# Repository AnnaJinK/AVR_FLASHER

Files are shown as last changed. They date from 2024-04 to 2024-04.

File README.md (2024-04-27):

## What is this?

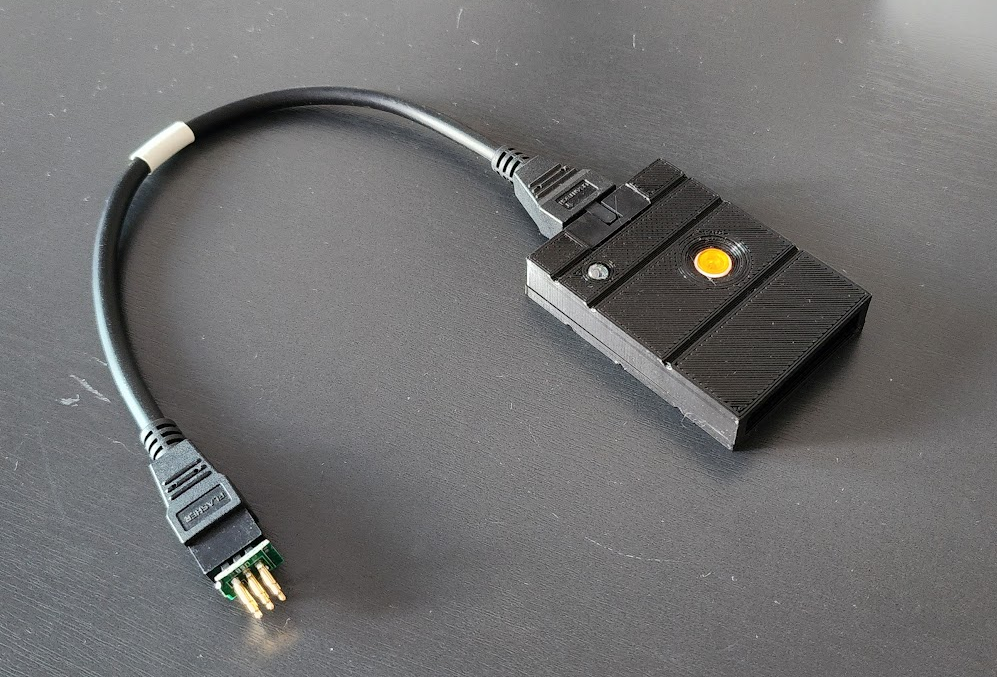
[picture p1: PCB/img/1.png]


SD 카드에 저장된 펌웨어를 타겟 AVR 장치로 플래싱하는 Standalone AVR Programmer 입니다.  
이 장치는 PC 가 필요없으며 간편하게 버튼 클릭만으로 타겟 장치의 IC 를 판별하여 펌웨어를 쓸수 있습니다.  
또한 ATtiny 부터 ATmega328PB 및 ATmega2560 등 ATmel 사의 다양한 AVR 을 지원합니다.

본 프로젝트는 [Gammon Forum](http://www.gammon.com.au/forum/?id=11638)의 내용을 바탕으로 제작되었습니다.

## Introduction

빌드된 펌웨어 파일 `firmaware.hex` 을 SD 카드에 옮겨준 후 장치에 삽입하고 버튼 만 누르면 됩니다.  
PlatformIO 에서 빌드된 펌웨어는 `firmaware.hex` 이름으로 `.pio/build` 폴더에 생성됩니다.  
ArduinoIDE 를 사용하는 경우 `Ctrl + Alt + S` 로 컴파일된 바이너리 파일 생성 후 `firmaware.hex` 로 이름을 바꿔서 사용하면 됩니다.

### Inside

PCB는 ATmega328P 제품을 사용하여 제작되었습니다.  
필요한 경우 ATmega2560 나 ATmega32u4 같은 다른 IC 를 사용하여 만들수도 있습니다.

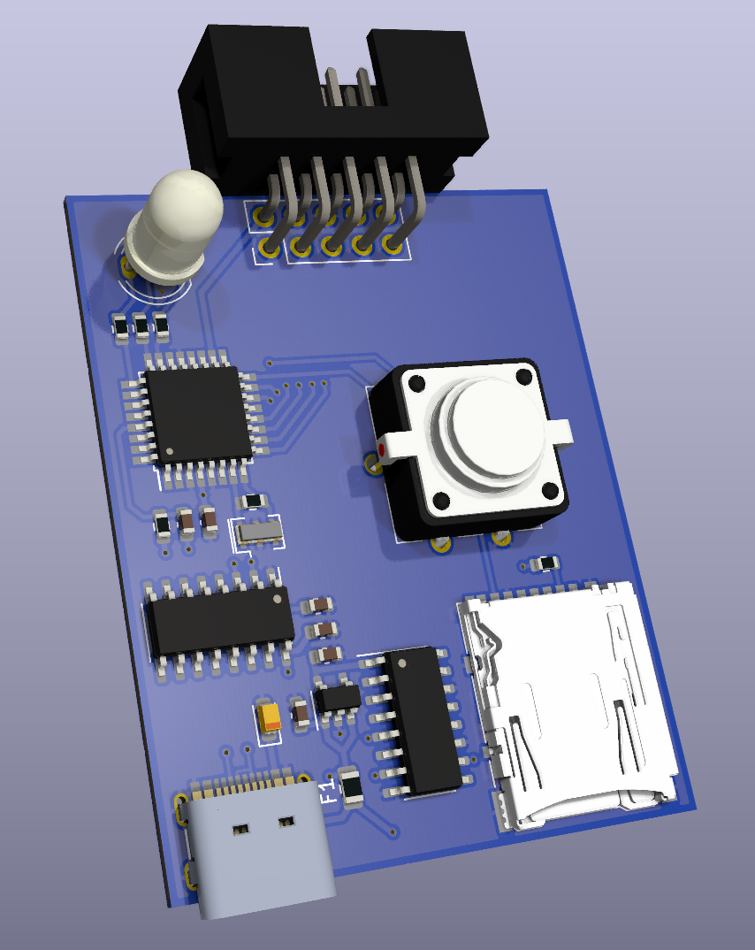
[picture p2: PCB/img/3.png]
  
  
USB C 포트는 시리얼 통신을 지원하며, 아두이노 부트로더 내장시 USB 를 통해 펌웨어를 쉽게 수정할 수 있습니다.  
부트로더가 내장되지 않은 IC 를 사용하는 경우 PCB 에 실장되는 IC를 위한 ICSP 가 없기 때문에 사전에 프로그램을 다운받는 것이 좋습니다.  
저렴하고 구하기쉬운 최소한의 부품들로 구성하였기 때문에 쉽게만들 수 있습니다.

자세한 내용은 [회로도](PCB/Schematic.pdf)를 참조하세요.

회로도와 부품 배치 데이터, 케이스 3D 모델, 거버파일은 PCB 폴더에 있습니다.

### Video

Video (https://youtu.be/CiSJQsz9dUg)

## CUSTOM FUSE

**이 기능은 사용시 주의가 필요합니다.**  
**CUSTOM FUSE 는 잘못 사용하면 IC 를 더 이상 사용할 수 없는 상태가 될 수 있습니다.**  
퓨즈 설정에 익숙하지 않다면 [퓨즈 계산기](https://www.engbedded.com/fusecalc/) 를 이용하는 것이 좋습니다.

`platformio.ini` 애서 CUSTOM_FUSE 활성화 방법입니다. (`ArduinoIDE` 는 스케치 상단에 정의합니다.)  
SD 카드를 사용하는 `CUSTOM_FUSE = 2`, `DEBUG_LV = 0` 가 기본 설정입니다.

```c
// File : platformio.ini
// @PlatformIO

build_flags =
; CUSTOM_FUSE 0 CUSTOM_FUSE 사용안함, 타겟 장치의 기본 세팅값 사용
; CUSTOM_FUSE 1 fuse.h 파일에 저장된 퓨즈세팅 사용
; CUSTOM_FUSE 2 SD 카드의 config.ini 파일로 부터 퓨즈 세팅 읽어옴
  -D CUSTOM_FUSE=2
; DEBUG_LV 0 디버그 모드 끔, 메모리 확보를 위해 끄는 것을 권장합니다
; DEBUG_LV 1 정의된 모든 동작을 모니터링
; DEBUG_LV 2 타겟 IC 식별과 SD 카드 퓨즈 세팅 동작 위주
  -D DEBUG_LV=0
  -D SERIAL_DISABLE=false ; 시리얼 통신 활성화
```

### `fuse.h` 파일을 사용한 CUSTOM_FUSE 설정

`platformio.ini` 의 내용을 다음과 같이 수정 한 후 AVR Programmer 에 업로드합니다.
```c
// File : platformio.ini
// @PlatformIO

build_flags =
  -D CUSTOM_FUSE=1
  -D DEBUG_LV=0
  -D SERIAL_DISABLE=true
```

`fuse.h` 를 사용한 방법은 메모리를 더 적게 사용하지만 장치를 매번 다시 컴파일 해줘야하는 단점이 있습니다.

```c
// File : src/fuse.h
/*
 * IC 와 퓨즈 정보를 아래 양식에 맞게 작성하여 사용합니다.
 * Available IC Table 에 정의된 이름과 동일하게 정의해야 합니다. (대소분자 구분)
 */
#ifdef ATmega32U4
#define AVR_CORE "ATmega32U4"
const byte low_fuses = 0xFF;
const byte high_fuses = 0xD8;
const byte extended_fuses = 0xCB;
const byte lock_bits = 0xFF;
#endif
```

`setting.h` 에 본인이 사용할 IC 를 정의합니다.
```c
// File : src/setting.h
#if CUSTOM_FUSE == 1
#define ATmega32U4  // 커스텀 퓨즈세팅을 사용할 IC 를 정의합니다.
#include "fuse.h"
byte custom_fuses[5] = {
    low_fuses,
    high_fuses,
    extended_fuses,
    lock_bits,
};
#elif CUSTOM_FUSE == 2
String AVR_CORE = "";
byte custom_fuses_sd[5];
#endif

```

### SD 카드의 `config.ini` 파일을 사용한 CUSTOM_FUSE 설정

SD 에 저장된 설정값을 사용하는 방법은 메모리를 조금 더 사용합니다.  
AVR Programmer의 펌웨어 변경없이 원하는 Fuse 값을 SD 카드에 넣어주기만 하면 되기 때문에 좀 더 편리합니다.  
단점으로 `DEBUG_LV 1` 과 함께 사용시 시스템 메모리가 2KB 이하인 IC는 메모리 부족으로 IC 가 리셋 될수 있습니다.  
따라서 CUSTOM FUSE 설정에 SD 카드 모드 사용시 `DEBUG_LV 0` 또는 `DEBUG_LV 2` 로 설정해야 합니다.

먼저 `platformio.ini` 의 내용을 다음과 같이 수정하여 AVR Programmer 에 업로드합니다
```c
// File : platformio.ini
// @PlatformIO

build_flags =
  -D CUSTOM_FUSE=2
  -D DEBUG_LV=0
  -D SERIAL_DISABLE=true
```

그 다음 SD 카드에 다음과 같이 `config.ini` 파일을 생성합니다.  
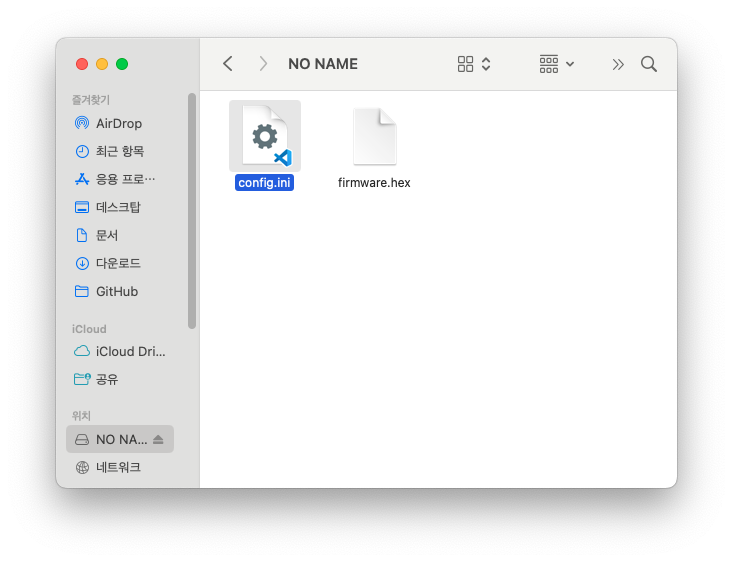
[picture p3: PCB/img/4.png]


`config.ini` 파일 내용은 다음과 같은 양식으로 작성합니다.

```
ATmega328P:FFDAFDFF
```

':' 를 구분 자로 사용하며 앞 쪽에는 IC 의 이름, 뒷 쪽에는 Fuse 설정을 적습니다.  
Fuse 의 순서는 왼쪽 부터 Low/High/Extended/Lockbits 입니다.

## Available IC Table

```c
// Atmega 칩들의 시그니처 코드입니다. 이 데이터들을 기준으로 타겟 칩을 인식합니다.
const signatureType signatures[] PROGMEM = {
    //     signature        description   flash size   bootloader  flash  fuse     timed
    //                                                     size    page    to      writes
    //                                                             size   change

    // Attiny84 family
    {{0x1E, 0x91, 0x0B}, "ATtiny24", 2 * kb, 0, 32, NO_FUSE, false},
    {{0x1E, 0x92, 0x07}, "ATtiny44", 4 * kb, 0, 64, NO_FUSE, false},
    {{0x1E, 0x93, 0x0C}, "ATtiny84", 8 * kb, 0, 64, NO_FUSE, false},

    // Attiny85 family
    {{0x1E, 0x91, 0x08}, "ATtiny25", 2 * kb, 0, 32, NO_FUSE, false},
    {{0x1E, 0x92, 0x06}, "ATtiny45", 4 * kb, 0, 64, NO_FUSE, false},
    {{0x1E, 0x93, 0x0B}, "ATtiny85", 8 * kb, 0, 64, NO_FUSE, false},

    // Atmega328 family
    {{0x1E, 0x92, 0x0A}, "ATmega48PA", 4 * kb, 0, 64, NO_FUSE, false},
    {{0x1E, 0x93, 0x0F}, "ATmega88PA", 8 * kb, 256, 128, extFuse, false},
    {{0x1E, 0x94, 0x0B}, "ATmega168PA", 16 * kb, 256, 128, extFuse, false},
    {{0x1E, 0x94, 0x06}, "ATmega168V", 16 * kb, 256, 128, extFuse, false},
    {{0x1E, 0x95, 0x0F}, "ATmega328P", 32 * kb, 512, 128, highFuse, false},
    {{0x1E, 0x95, 0x16}, "ATmega328PB", 32 * kb, 512, 128, highFuse, false},
    {{0x1E, 0x95, 0x14}, "ATmega328", 32 * kb, 512, 128, highFuse, false},

    // Atmega644 family
    {{0x1E, 0x94, 0x0A}, "ATmega164P", 16 * kb, 256, 128, highFuse, false},
    {{0x1E, 0x95, 0x08}, "ATmega324P", 32 * kb, 512, 128, highFuse, false},
    {{0x1E, 0x96, 0x0A}, "ATmega644P", 64 * kb, 1 * kb, 256, highFuse, false},

    // Atmega2560 family
    {{0x1E, 0x96, 0x08}, "ATmega640", 64 * kb, 1 * kb, 256, highFuse, false},
    {{0x1E, 0x97, 0x03}, "ATmega1280", 128 * kb, 1 * kb, 256, highFuse, false},
    {{0x1E, 0x97, 0x04}, "ATmega1281", 128 * kb, 1 * kb, 256, highFuse, false},
    {{0x1E, 0x98, 0x01}, "ATmega2560", 256 * kb, 1 * kb, 256, highFuse, false},

    {{0x1E, 0x98, 0x02}, "ATmega2561", 256 * kb, 1 * kb, 256, highFuse, false},

    // AT90USB family
    {{0x1E, 0x93, 0x82}, "At90USB82", 8 * kb, 512, 128, highFuse, false},
    {{0x1E, 0x94, 0x82}, "At90USB162", 16 * kb, 512, 128, highFuse, false},

    // Atmega32U2 family
    {{0x1E, 0x93, 0x89}, "ATmega8U2", 8 * kb, 512, 128, highFuse, false},
    {{0x1E, 0x94, 0x89}, "ATmega16U2", 16 * kb, 512, 128, highFuse, false},
    {{0x1E, 0x95, 0x8A}, "ATmega32U2", 32 * kb, 512, 128, highFuse, false},

    // Atmega32U4 family -  (datasheet is wrong about flash page size being 128 words)
    {{0x1E, 0x94, 0x88}, "ATmega16U4", 16 * kb, 512, 128, highFuse, false},
    {{0x1E, 0x95, 0x87}, "ATmega32U4", 32 * kb, 512, 128, highFuse, false},

    // ATmega1284P family
    {{0x1E, 0x97, 0x05}, "ATmega1284P", 128 * kb, 1 * kb, 256, highFuse, false},
    {{0x1E, 0x97, 0x06}, "ATmega1284", 128 * kb, 1 * kb, 256, highFuse, false},

    // ATtiny4313 family
    {{0x1E, 0x91, 0x0A}, "ATtiny2313A", 2 * kb, 0, 32, NO_FUSE, false},
    {{0x1E, 0x92, 0x0D}, "ATtiny4313", 4 * kb, 0, 64, NO_FUSE, false},

    // ATtiny13 family
    {{0x1E, 0x90, 0x07}, "ATtiny13A", 1 * kb, 0, 32, NO_FUSE, false},

    // Atmega8A family
    {{0x1E, 0x93, 0x07}, "ATmega8A", 8 * kb, 256, 64, highFuse, true},

    // ATmega64rfr2 family
    {{0x1E, 0xA6, 0x02}, "ATmega64rfr2", 256 * kb, 1 * kb, 256, highFuse, false},
    {{0x1E, 0xA7, 0x02}, "ATmega128rfr2", 256 * kb, 1 * kb, 256, highFuse, false},
    {{0x1E, 0xA8, 0x02}, "ATmega256rfr2", 256 * kb, 1 * kb, 256, highFuse, false},

};
```

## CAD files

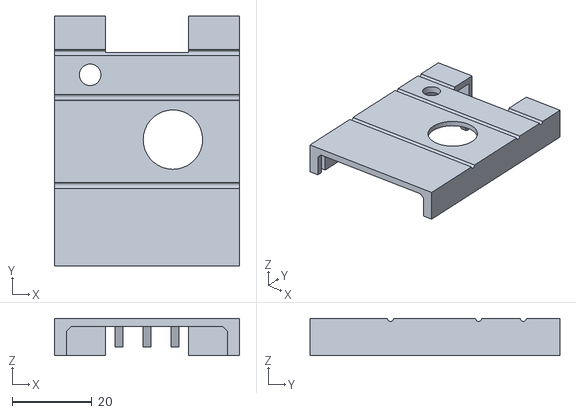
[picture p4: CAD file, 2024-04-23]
PCB/3D Print CASE/AVR_FLASHER - SLIM_TOP.STL
46.4 x 62.7 x 9.30

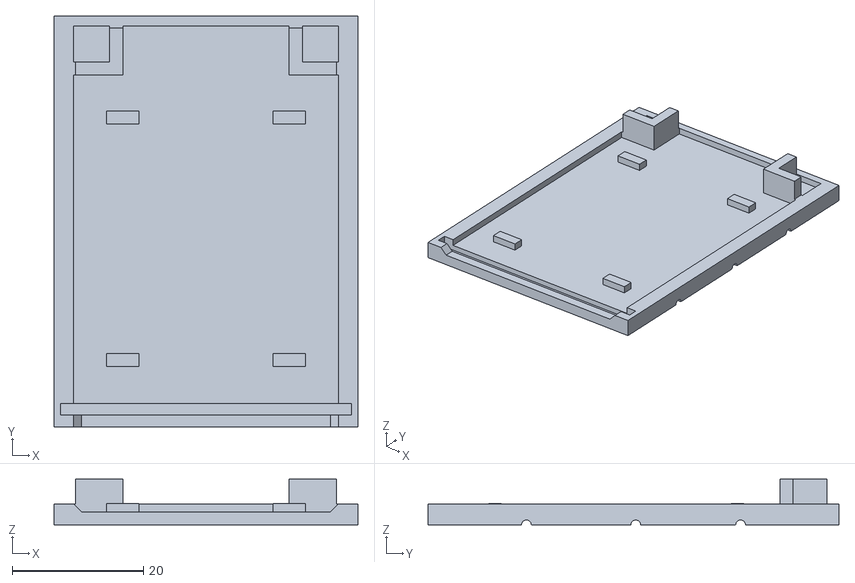
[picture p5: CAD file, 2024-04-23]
PCB/3D Print CASE/AVR_FLASHER - SLIM_BOT.STL
46.4 x 62.7 x 7.00

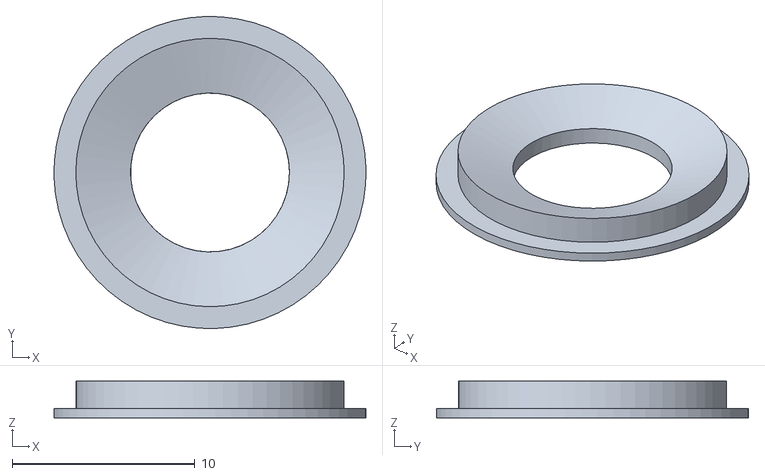
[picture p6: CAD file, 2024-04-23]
PCB/3D Print CASE/AVR_FLASHER - SLIM_HOLE.STL
17.1 x 17.1 x 2.00

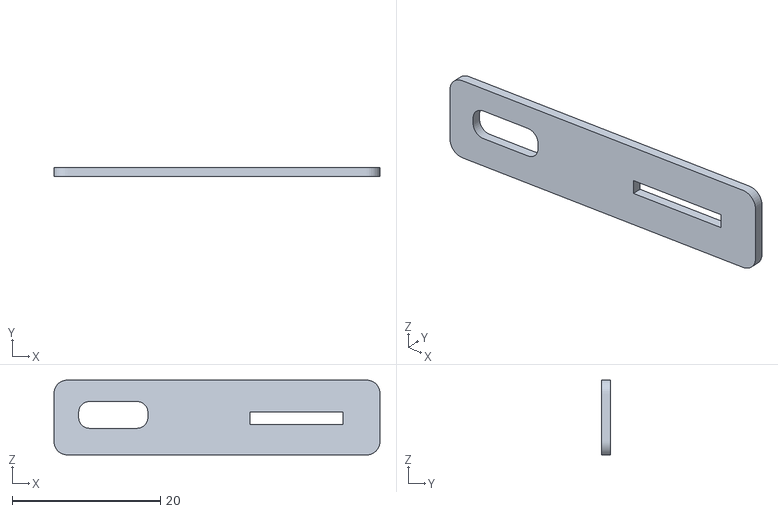
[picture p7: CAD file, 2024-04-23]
PCB/3D Print CASE/AVR_FLASHER - SLIM_IO.STL
44.0 x 1.20 x 10.1

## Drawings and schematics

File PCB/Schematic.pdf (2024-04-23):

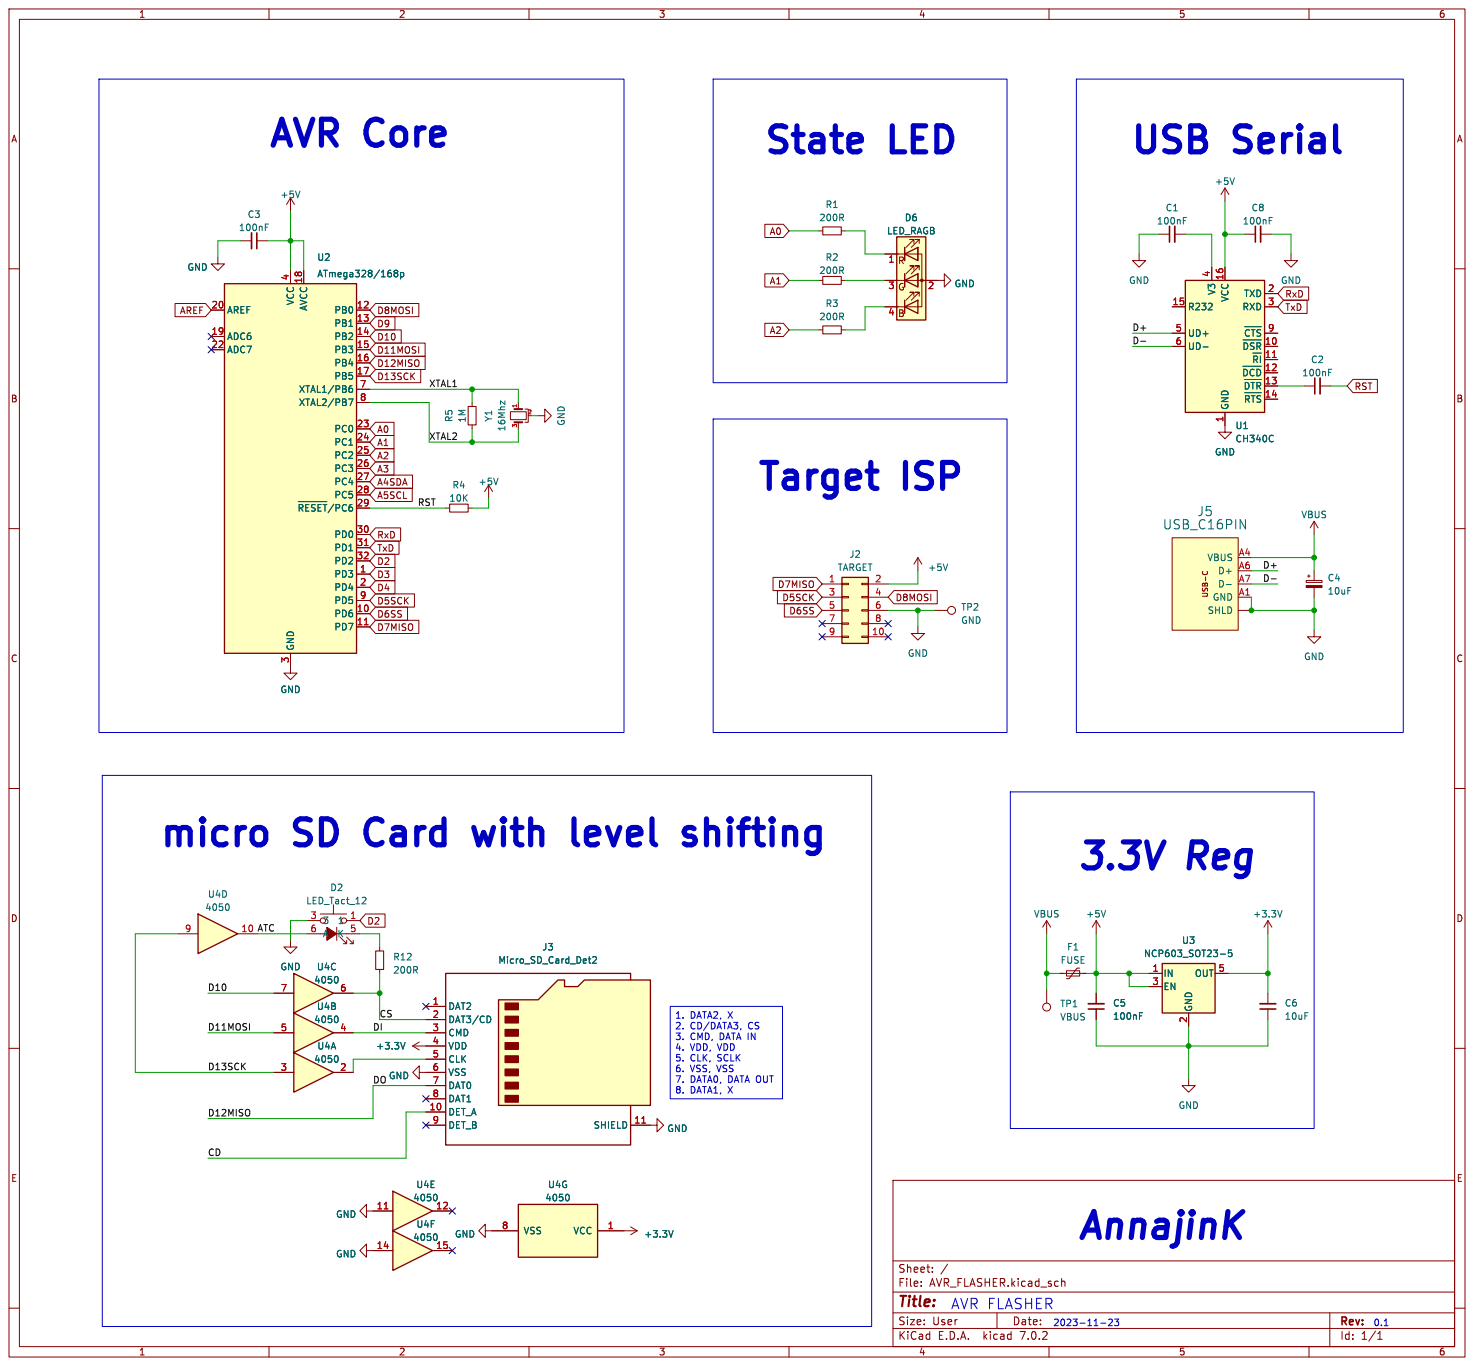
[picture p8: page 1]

1 ~{DSR} 10 ~{RI} 11 ~{DCD} 12 ~{DTR} 13 ~{RTS} 14 R232 15 VCC 16 TXD 2 RXD 3 V3

4 UD+ 5 UD- 6 ~{CTS}9 GND

100nF GND USB-C GND A1 VBUS A4 D+ A6 D- A7 SHLD

2023-11-23 3.3V Reg micro SD Card with level shifting

Id: 1/1 Title: File: AVR_FLASHER.kicad_sch Sheet: /

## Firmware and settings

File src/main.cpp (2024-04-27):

#include <Arduino.h>
#include <SDFat.h>
#include <sdios.h>

#include "setting.h"

// SD 카드에서 읽을 고정 파일 이름 (루트 디렉터리)
const char wantedFile[] = "firmware.hex";
const char configFile[] = "config.ini";

/*
  For more details, photos, wiring, instructions, see:
    http://www.gammon.com.au/forum/?id=11638
  Copyright 2012 Nick Gammon. Addeded code forr fuse burning by Dan Geiger 2023.


  PERMISSION TO DISTRIBUTE

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

  LIMITATION OF LIABILITY

  The software is provided "as is", without warranty of any kind, express or implied,
  including but not limited to the warranties of merchantability, fitness for a particular
  purpose and noninfringement. In no event shall the authors or copyright holders be liable
  for any claim, damages or other liability, whether in an action of contract,
  tort or otherwise, arising from, out of or in connection with the software
  or the use or other dealings in the software.
*/

// const char Version[] = "1.3dg";

// file system object
SdFat sd;

// 각 칩에 대한 시그니처 및 기타 관련 데이터를 저장하는 구조체
#include "signature.h"

// 함수 선언
void writeFuse(const byte newValue, const byte instruction);

//"times" 만큼 "interval" 지연시간으로 한 개 또는 두 개의 LED를 깜박입니다.
// 깜빡임 동작은 1초 대기 후 "repeat" 횟수만큼 다시 반복됩니다
void blink(const int whichLED1, const int whichLED2, const byte times = 1, const unsigned long repeat = 1, const unsigned long interval = 100) {
    for (unsigned long i = 0; i < repeat; i++) {
        for (byte j = 0; j < times; j++) {
            digitalWrite(whichLED1, HIGH);
            if (whichLED2 != noLED) digitalWrite(whichLED2, HIGH);
            delay(interval);
            digitalWrite(whichLED1, LOW);
            if (whichLED2 != noLED) digitalWrite(whichLED2, LOW);
            delay(interval);
        }  // end of for loop
        if (i < (repeat - 1)) delay(10);
    }  // end of repeating the sequence
}  // end of blink

void ShowMessage(const byte which) {
    // first turn off all LEDs
    digitalWrite(errorLED, LOW);
    digitalWrite(workingLED, LOW);
    digitalWrite(readyLED, LOW);

    // now flash an appropriate sequence
    switch (which) {
        // problems with SD card or finding the file
        case MSG_NO_SD_CARD:
            debugln_1("MSG_NO_SD_CARD");
            blink(errorLED, noLED, 1, 5);
            break;
        case MSG_CANNOT_OPEN_FILE:
            debugln_1("MSG_CANNOT_OPEN_FILE");
            blink(errorLED, noLED, 2, 5);
            while (!sd.begin(chipSelect, SPI_FULL_SPEED)) {
                ShowMessage(MSG_NO_SD_CARD);
                delay(500);
            }
            break;

        // problems reading the .hex file
        case MSG_LINE_TOO_LONG:
            debugln_1("MSG_LINE_TOO_LONG");
            blink(errorLED, workingLED, 1, 5);
            break;
        case MSG_LINE_TOO_SHORT:
            debugln_1("MSG_LINE_TOO_SHORT");
            blink(errorLED, workingLED, 2, 5);
            break;
        case MSG_LINE_DOES_NOT_START_WITH_COLON:
            debugln_1("MSG_LINE_DOES_NOT_START_WITH_COLON");
            blink(errorLED, workingLED, 3, 5);
            break;
        case MSG_INVALID_HEX_DIGITS:
            debugln_1("MSG_INVALID_HEX_DIGITS");
            blink(errorLED, workingLED, 4, 5);
            break;
        case MSG_BAD_SUMCHECK:
            debugln_1("MSG_BAD_SUMCHECK");
            blink(errorLED, workingLED, 5, 5);
            break;
        case MSG_LINE_NOT_EXPECTED_LENGTH:
            debugln_1("MSG_LINE_NOT_EXPECTED_LENGTH");
            blink(errorLED, workingLED, 6, 5);
            break;
        case MSG_UNKNOWN_RECORD_TYPE:
            debugln_1("MSG_UNKNOWN_RECORD_TYPE");
            blink(errorLED, workingLED, 7, 5);
            break;
        case MSG_NO_END_OF_FILE_RECORD:
            debugln_1("MSG_NO_END_OF_FILE_RECORD");
            blink(errorLED, workingLED, 8, 5);
            break;

        // problems with the file contents
        case MSG_FILE_TOO_LARGE_FOR_FLASH:
            debugln_1("MSG_FILE_TOO_LARGE_FOR_FLASH");
            blink(errorLED, workingLED, 9, 5);
            break;

        // problems programming the chip
        case MSG_CANNOT_ENTER_PROGRAMMING_MODE:
            debugln_1("MSG_CANNOT_ENTER_PROGRAMMING_MODE");
            blink(errorLED, noLED, 3, 5);
            break;
        case MSG_NO_BOOTLOADER_FUSE:
            debugln_1("MSG_NO_BOOTLOADER_FUSE");
            blink(errorLED, noLED, 4, 5);
            break;
        case MSG_CANNOT_FIND_SIGNATURE:
            debugln_1("MSG_CANNOT_FIND_SIGNATURE");
            blink(errorLED, noLED, 5, 5);
            break;
        case MSG_UNRECOGNIZED_SIGNATURE:
            debugln_1("MSG_UNRECOGNIZED_SIGNATURE");
            blink(errorLED, noLED, 6, 5);
            break;
        case MSG_BAD_START_ADDRESS:
            debugln_1("MSG_BAD_START_ADDRESS");
            blink(errorLED, noLED, 7, 5);
            break;
        case MSG_VERIFICATION_ERROR:
            debugln_1("MSG_VERIFICATION_ERROR");
            blink(errorLED, noLED, 8, 5);
            break;
        case MSG_FUSE_PROBLEM:
            debugln_1("MSG_FUSE_PROBLEM");
            blink(errorLED, noLED, 9, 5);
            break;
        case MSG_FLASHED_OK:
            debugln_1("MSG_FLASHED_OK");
            blink(readyLED, noLED, 3, 1);
            break;

        default:
            blink(errorLED, 11, 10);
            break;  // unknown error
    }  // end of switch on which message
}  // end of ShowMessage

// Bit Banged SPI transfer
byte BB_SPITransfer(byte c) {
    byte bit;

    for (bit = 0; bit < 8; bit++) {
        // write MOSI on falling edge of previous clock
        if (c & 0x80)
            BB_MOSI_PORT |= bit(BB_MOSI_BIT);
        else
            BB_MOSI_PORT &= ~bit(BB_MOSI_BIT);
        c <<= 1;

        // read MISO
        c |= (BB_MISO_PORT & bit(BB_MISO_BIT)) != 0;

        // clock high
        BB_SCK_PORT |= bit(BB_SCK_BIT);

        // delay between rise and fall of clock
        delayMicroseconds(BB_DELAY_MICROSECONDS);

        // clock low
        BB_SCK_PORT &= ~bit(BB_SCK_BIT);

        // delay between rise and fall of clock
        delayMicroseconds(BB_DELAY_MICROSECONDS);
    }

    return c;
}  // end of BB_SPITransfer

// 만약 위 테이블에서 시그니처를 찾았다면, foundSig 는 해당 시그니처의 인덱스입니다.
int foundSig = -1;
byte lastAddressMSB = 0;
// 일치하는 프로세서를 위한 현재 시그니처 항목의 사본입니다.
signatureType currentSignature;

// 한 개의 프로그래밍 명령어를 실행합니다. ... b1은 명령, b2, b3, b4는 인수입니다.
// 프로세서는 4번째 전송에서 결과를 반환할 수 있습니다. 이를 반환합니다.
byte program(const byte b1, const byte b2 = 0, const byte b3 = 0, const byte b4 = 0) {
    noInterrupts();
    BB_SPITransfer(b1);
    BB_SPITransfer(b2);
    BB_SPITransfer(b3);
    byte b = BB_SPITransfer(b4);
    interrupts();
    return b;
}  // end of program

// read a byte from flash memory
byte readFlash(unsigned long addr) {
    byte high = (addr & 1) ? 0x08 : 0;  // set if high byte wanted
    addr >>= 1;                         // turn into word address

    // set the extended (most significant) address byte if necessary
    byte MSB = (addr >> 16) & 0xFF;
    if (MSB != lastAddressMSB) {
        program(loadExtendedAddressByte, 0, MSB);
        lastAddressMSB = MSB;
    }  // end if different MSB

    return program(readProgramMemory | high, highByte(addr), lowByte(addr));
}  // end of readFlash

// write a byte to the flash memory buffer (ready for committing)
void writeFlash(unsigned long addr, const byte data) {
    byte high = (addr & 1) ? 0x08 : 0;  // set if high byte wanted
    addr >>= 1;                         // turn into word address
    program(loadProgramMemory | high, 0, lowByte(addr), data);
}  // end of writeFlash

// 두 개의 16진수 문자를 바이트로 변환합니다.
// 에러인 경우 true를 반환하고, 정상인 경우 false를 반환합니다.
bool hexConv(const char *(&pStr), byte &b) {
    if (!isxdigit(pStr[0]) || !isxdigit(pStr[1])) {
        ShowMessage(MSG_INVALID_HEX_DIGITS);
        return true;
    }  // end not hex

    b = *pStr++ - '0';
    if (b > 9) b -= 7;

    // high-order nybble
    b <<= 4;

    byte b1 = *pStr++ - '0';
    if (b1 > 9) b1 -= 7;

    b |= b1;

    return false;  // OK
}  // end of hexConv

// 타겟 장치가 프로그래밍할 준비가 될 때까지 대기합니다.
void pollUntilReady() {
    if (currentSignature.timedWrites)
        delay(10);  // at least 2 x WD_FLASH which is 4.5 mS
    else {
        while ((program(pollReady) & 1) == 1) {
        }  // wait till ready
    }  // end of if
}  // end of pollUntilReady

unsigned long pagesize;
unsigned long pagemask;
unsigned long oldPage;
unsigned int progressBarCount;

// shows progress, toggles working LED
void showProgress() { digitalWrite(workingLED, !digitalRead(workingLED)); }  // end of showProgress

// 모든 임시 페이지를 0xFF로 지웁니다. 만약 모두 기록하지 않는 경우를 대비합니다.
void clearPage() {
    unsigned int len = currentSignature.pageSize;
    for (unsigned int i = 0; i < len; i++) writeFlash(i, 0xFF);
}  // end of clearPage

// 페이지를 플래시 메모리에 기록합니다.
void commitPage(unsigned long addr) {
    addr >>= 1;  // turn into word address

    // set the extended (most significant) address byte if necessary
    byte MSB = (addr >> 16) & 0xFF;
    if (MSB != lastAddressMSB) {
        program(loadExtendedAddressByte, 0, MSB);
        lastAddressMSB = MSB;
    }  // end if different MSB

    showProgress();

    program(writeProgramMemory, highByte(addr), lowByte(addr));
    pollUntilReady();

    clearPage();  // clear ready for next page full
}  // end of commitPage

// 커밋할 준비가 된 임시 버퍼에 데이터를 씁니다.
void writeData(const unsigned long addr, const byte *pData, const int length) {
    // write each byte
    for (int i = 0; i < length; i++) {
        unsigned long thisPage = (addr + i) & pagemask;
        // page changed? commit old one
        if (thisPage != oldPage && oldPage != NO_PAGE) commitPage(oldPage);
        // now this is the current page
        oldPage = thisPage;
        // put byte into work buffer
        writeFlash(addr + i, pData[i]);
    }  // end of for

}  // end of writeData

// count errors
unsigned int errors;

void verifyData(const unsigned long addr, const byte *pData, const int length) {
    // check each byte
    for (int i = 0; i < length; i++) {
        unsigned long thisPage = (addr + i) & pagemask;
        // page changed? show progress
        if (thisPage != oldPage && oldPage != NO_PAGE) showProgress();
        // now this is the current page
        oldPage = thisPage;

        byte found = readFlash(addr + i);
        byte expected = pData[i];
        if (found != expected) {
            errors++;
        }
    }  // end of for

}  // end of verifyData

bool gotEndOfFile;
unsigned long extendedAddress;

unsigned long lowestAddress;
unsigned long highestAddress;
unsigned long bytesWritten;
unsigned int lineCount;

/*
  Line format:
  :nnaaaatt(data)ss

  Where:
  :      = a colon (hex line follows)
  F      = Fuse command follows (FaXX - a(L=low, H=high, E=extended, B=LockByte, C=calibration) - XX = value)

  (All of below in hex format)

  nn     = length of data part
  aaaa   = address (eg. where to write data)
  tt     = transaction type
           00 = data
           01 = end of file
           02 = extended segment address (changes high-order byte of the address)
           03 = start segment address *
           04 = linear address *
           05 = start linear address *
  (data) = variable length data
  ss     = sumcheck
              We don't use these

*/

// returns true if error, false if OK
bool processLine(const char *pLine, const byte action) {
    if (*pLine++ != ':') {
        ShowMessage(MSG_LINE_DOES_NOT_START_WITH_COLON);
        return true;  // error
    }

    const int maxHexData = 40;
    byte hexBuffer[maxHexData];
    int bytesInLine = 0;

    if (action == checkFile)
        if (lineCount++ % 40 == 0) showProgress();

    // convert entire line from ASCII into binary
    while (isxdigit(*pLine)) {
        // can't fit?
        if (bytesInLine >= maxHexData) {
            ShowMessage(MSG_LINE_TOO_LONG);
            return true;
        }  // end if too long

        if (hexConv(pLine, hexBuffer[bytesInLine++])) return true;
    }  // end of while

    if (bytesInLine < 5) {
        ShowMessage(MSG_LINE_TOO_SHORT);
        return true;
    }

    // sumcheck it

    byte sumCheck = 0;
    for (int i = 0; i < (bytesInLine - 1); i++) sumCheck += hexBuffer[i];

    // 2's complement
    sumCheck = ~sumCheck + 1;

    // check sumcheck
    if (sumCheck != hexBuffer[bytesInLine - 1]) {
        ShowMessage(MSG_BAD_SUMCHECK);
        return true;
    }

    // length of data (eg. how much to write to memory)
    byte len = hexBuffer[0];

    // the data length should be the number of bytes, less
    //   length / address (2) / transaction type / sumcheck
    if (len != (bytesInLine - 5)) {
        ShowMessage(MSG_LINE_NOT_EXPECTED_LENGTH);
        return true;
    }

    // two bytes of address
    unsigned long addrH = hexBuffer[1];
    unsigned long addrL = hexBuffer[2];

    unsigned long addr = addrL | (addrH << 8);

    byte recType = hexBuffer[3];

    switch (recType) {
        // stuff to be written to memory
        case hexDataRecord:
            lowestAddress = min(lowestAddress, addr + extendedAddress);
            highestAddress = max(lowestAddress, addr + extendedAddress + len - 1);
            bytesWritten += len;

            switch (action) {
                case checkFile:  // nothing much to do, we do the checks anyway
                    break;

                case verifyFlash:
                    verifyData(addr + extendedAddress, &hexBuffer[4], len);
                    break;

                case writeToFlash:
                    writeData(addr + extendedAddress, &hexBuffer[4], len);
                    break;
            }  // end of switch on action
            break;

        // end of data
        case hexEndOfFile:
            gotEndOfFile = true;
            break;

        // we are setting the high-order byte of the address
        case hexExtendedSegmentAddressRecord:
            extendedAddress = ((unsigned long)hexBuffer[4]) << 12;
            break;

        // ignore these, who cares?
        case hexStartSegmentAddressRecord:
        case hexExtendedLinearAddressRecord:
        case hexStartLinearAddressRecord:
            break;

        default:
            ShowMessage(MSG_UNKNOWN_RECORD_TYPE);
            return true;
    }  // end of switch on recType

    return false;
}  // end of processLine

#if CUSTOM_FUSE == 2
/*
ATmega328P:FFDEFDFF
*/
bool parseLine(const char *pLine) {
    char *token = strtok(const_cast<char *>(pLine), ":");
    if (token == nullptr) {
        // Error: No delimiter found
        return true;
    }
    debugln_2("\nDevice Setting from Config.ini File!!");
    String strToken(token);
    debug_2("IC : ");
    debugln_2(strToken);
    AVR_CORE = strToken;

    // Extract hex data
    token = strtok(nullptr, ":");
    if (token == nullptr) {
        // Error: No hex data found after delimiter
        return true;
    }
    String hexData(token);
    debug_2("Fuse Bits: ");
    debug_2(hexData);
    debugln_2(" (Low/High/Extended/Lock)");
    // Convert hex data to bytes
    char hexByte[3];
    int index = 0;
    while (hexData.length() >= 2) {
        hexByte[0] = hexData.charAt(0);
        hexByte[1] = hexData.charAt(1);
        hexByte[2] = '\0';
        byte value = strtol(hexByte, nullptr, 16);
        // debug_2("Byte: ");
        // debugln_2(value, HEX);
        custom_fuses_sd[index] = value;
        hexData.remove(0, 2);
        index++;
    }
    debugln_2("Device Setting End.\n");
    return false;
}

bool readConfigFile(const char *fName) {
    const int maxLine = 40;
    ifstream sdin(fName);
    char buffer[maxLine];

    if (!sdin.is_open()) {
        Serial.println("Config.ini not found!");
        return true;
    }

    while (sdin.getline(buffer, maxLine)) {
        int count = sdin.gcount();
        if (sdin.fail()) {
            debugln_2(MSG_LINE_TOO_LONG);
            return true;
        }
        if (count > 1) {
            if (parseLine(buffer)) {
                return true;
            }
        }
    }
    return false;
}
#endif

//------------------------------------------------------------------------------
// returns true if error, false if OK
bool readHexFile(const char *fName, const byte action) {
    const int maxLine = 80;
    char buffer[maxLine];
    ifstream sdin(fName);
    int lineNumber = 0;
    gotEndOfFile = false;
    extendedAddress = 0;
    errors = 0;
    lowestAddress = 0xFFFFFFFF;
    highestAddress = 0;
    bytesWritten = 0;
    progressBarCount = 0;

    pagesize = currentSignature.pageSize;
    pagemask = ~(pagesize - 1);
    oldPage = NO_PAGE;

    // check for open error
    if (!sdin.is_open()) {
        ShowMessage(MSG_CANNOT_OPEN_FILE);
        return true;
    }

    switch (action) {
        case checkFile:
            break;

        case verifyFlash:
            debugln_1("MSG_VERIFY_FLASH");
            break;

        case writeToFlash:
            debugln_1("MSG_WRITE_TO_FLASH");
            program(progamEnable, chipErase);  // erase it
            delay(20);                         // for Atmega8
            pollUntilReady();
            clearPage();  // clear temporary page
            break;
    }  // end of switch

    while (sdin.getline(buffer, maxLine)) {
        lineNumber++;

        int count = sdin.gcount();

        if (sdin.fail()) {
            ShowMessage(MSG_LINE_TOO_LONG);
            return true;
        }  // end of fail (line too long?)

        // ignore empty lines
        if (count > 1) {
            if (processLine(buffer, action)) {
                return true;  // error
            }
        }
    }  // end of while each line

    if (!gotEndOfFile) {
        ShowMessage(MSG_NO_END_OF_FILE_RECORD);
        return true;
    }

    switch (action) {
        case writeToFlash:
            // commit final page
            if (oldPage != NO_PAGE) commitPage(oldPage);
            break;

        case verifyFlash:
            if (errors > 0) {
                ShowMessage(MSG_VERIFICATION_ERROR);
                return true;
            }  // end if
            break;

        case checkFile:
            break;
    }  // end of switch

    return false;
}  // end of readHexFile

// returns true if managed to enter programming mode
bool startProgramming() {
    debugln_1("MSG_START_PROGRAMMING");
    byte confirm;
    pinMode(RESET, OUTPUT);
    digitalWrite(MSPIM_SCK, LOW);
    pinMode(MSPIM_SCK, OUTPUT);
    pinMode(BB_MOSI, OUTPUT);
    unsigned int timeout = 0;

    // we are in sync if we get back programAcknowledge on the third byte
    do {
        // regrouping pause
        delay(100);

        // ensure SCK low
        noInterrupts();
        digitalWrite(MSPIM_SCK, LOW);
        // then pulse reset, see page 309 of datasheet
        digitalWrite(RESET, HIGH);
        delayMicroseconds(10);  // pulse for at least 2 clock cycles
        digitalWrite(RESET, LOW);
        interrupts();

        delay(25);  // wait at least 20 mS
        noInterrupts();
        BB_SPITransfer(progamEnable);
        BB_SPITransfer(programAcknowledge);
        confirm = BB_SPITransfer(0);
        BB_SPITransfer(0);
        interrupts();

        if (confirm != programAcknowledge) {
            if (timeout++ >= ENTER_PROGRAMMING_ATTEMPTS) return false;
        }  // end of not entered programming mode

    } while (confirm != programAcknowledge);
    return true;  // entered programming mode OK
}  // end of startProgramming

void stopProgramming() {
    // turn off pull-ups
    digitalWrite(RESET, LOW);
    digitalWrite(MSPIM_SCK, LOW);
    digitalWrite(BB_MOSI, LOW);
    digitalWrite(BB_MISO, LOW);

    // set everything back to inputs
    pinMode(RESET, INPUT);
    pinMode(MSPIM_SCK, INPUT);
    pinMode(BB_MOSI, INPUT);
    pinMode(BB_MISO, INPUT);

}  // end of stopProgramming

void getSignature() {
    foundSig = -1;
    lastAddressMSB = 0;

    byte sig[3];
    for (byte i = 0; i < 3; i++) {
        sig[i] = program(readSignatureByte, 0, i);
    }  // end for each signature byte

    for (unsigned int j = 0; j < NUMITEMS(signatures); j++) {
        memcpy_P(&currentSignature, &signatures[j], sizeof currentSignature);

        if (memcmp(sig, currentSignature.sig, sizeof sig) == 0) {
            foundSig = j;
            // make sure extended address is zero to match lastAddressMSB variable
            debugln_1("MSG_RECOGNIZED_SIGNATURE");
            program(loadExtendedAddressByte, 0, 0);
            return;
        }  // end of signature found
    }  // end of for each signature
    ShowMessage(MSG_UNRECOGNIZED_SIGNATURE);
}  // end of getSignature
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
void loop() {
    digitalWrite(readyLED, HIGH);
#if CUSTOM_FUSE == 2
    // config.ini 로 부터 퓨즈 데이터를 읽어옵니다.
    // 2KB 이하의 시스템 메모리의 IC 에서 DEBUG 옵션 true 사용시
    // FUSE_FROM_SD_CARD 기능을 활성화 하면 메모리 부족으로 장치가 리셋 될 수 있습니다.
    readConfigFile(configFile);
#endif
    // wait till they press the start switch
    while (digitalRead(startSwitch) == HIGH) {
    }  // end of waiting for switch press
    // printMemoryUsage(); // 메모리 출력
    strcpy(name, wantedFile);  // use fixed name

    digitalWrite(readyLED, LOW);

    if (!startProgramming()) {
        ShowMessage(MSG_CANNOT_ENTER_PROGRAMMING_MODE);
        return;
    }  // end of could not enter programming mode

    getSignature();

    getFuseBytes();

    // don't have signature? don't proceed
    if (foundSig == -1) {
        ShowMessage(MSG_CANNOT_FIND_SIGNATURE);
        return;
    }  // end of no signature

    digitalWrite(workingLED, HIGH);
    bool ok = writeFlashContents();
    digitalWrite(workingLED, LOW);
    digitalWrite(readyLED, LOW);
    stopProgramming();
    delay(100);

    if (ok) {
        ShowMessage(MSG_FLASHED_OK);
    }

}  // end of loop

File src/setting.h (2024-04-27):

#ifndef SETTING_H
#define SETTING_H

#ifndef Arduino_h
#include <Arduino.h>
#endif

#if DEBUG_LV == 1
#define debug_1(...) Serial.print(__VA_ARGS__)
#define debugln_1(...) Serial.println(__VA_ARGS__)
#define debug_2(...) Serial.print(__VA_ARGS__)
#define debugln_2(...) Serial.println(__VA_ARGS__)
#elif DEBUG_LV == 2
#define debug_1(...)
#define debugln_1(...)
#define debug_2(...) Serial.print(__VA_ARGS__)
#define debugln_2(...) Serial.println(__VA_ARGS__)
#else
#define debug_1(...)
#define debugln_1(...)
#define debug_2(...)
#define debugln_2(...)
#endif

/**
 * @brief CUSTOM_FUSE 를 설정합니다.
 * 커스텀 퓨즈 세팅을 사용할경우 1, 2
 * 사전 설정된 퓨즈세팅을 사용할 경우 0
 * #define CUSTOM_FUSE
 */
#if CUSTOM_FUSE == 1
#define ATmega32U4  // 커스텀 퓨즈세팅을 사용할 IC 를 정의합니다.
#include "fuse.h"
byte custom_fuses[5] = {
    low_fuses,
    high_fuses,
    extended_fuses,
    lock_bits,
};
#elif CUSTOM_FUSE == 2
String AVR_CORE = "";
byte custom_fuses_sd[5];
#endif

// copy of fuses/lock bytes found for this processor
byte fuses[5];

// Crossroads 보드를 사용하는 경우 LED 표시와 로터리 인코더가 있는지 여부를 지정합니다.
#define CROSSROADS_PROGRAMMING_BOARD false
// 파일 이름을 변경하는 데 로터리 인코더가 없는 보드인 경우 true로 설정합니다.
#define NO_ENCODER true
// 16진수 파일 이름을 사용하려는 경우 true로 설정합니다. (즉, 00에서 FF까지, 00에서 99가 아닌)
#define HEX_FILE_NAMES true

const bool allowTargetToRun = true;  // true이면 프로그래밍이 아닐 때 프로그래밍 라인이 해제됩니다.

// status "messages"
typedef enum {
    MSG_NO_SD_CARD,                      // SD 카드를 열 수 없음
    MSG_CANNOT_OPEN_FILE,                // 'wantedFile' 파일을 열 수 없음 (위에 정의됨)
    MSG_LINE_TOO_LONG,                   // 디스크의 줄이 너무 깁니다.
    MSG_LINE_TOO_SHORT,                  // 유효하지 않은 줄이 너무 짧습니다.
    MSG_LINE_DOES_NOT_START_WITH_COLON,  // 줄이 콜론으로 시작하지 않습니다.
    MSG_INVALID_HEX_DIGITS,              // 16진수가 아닌 부분이 있습니다.
    MSG_BAD_SUMCHECK,                    // 줄의 체크섬이 잘못되었습니다.
    MSG_LINE_NOT_EXPECTED_LENGTH,        // 기대하는 길이의 레코드가 아닙니다.
    MSG_UNKNOWN_RECORD_TYPE,             // 알 수 없는 레코드 유형입니다.
    MSG_NO_END_OF_FILE_RECORD,           // 파일 끝에 'end of file'이 없습니다.
    MSG_FILE_TOO_LARGE_FOR_FLASH,        // 파일 크기가 플래시에 맞지 않습니다

    MSG_CANNOT_ENTER_PROGRAMMING_MODE,  // 타겟 칩을 프로그래밍할 수 없습니다.
    MSG_NO_BOOTLOADER_FUSE,             // 칩에 부트로더가 없습니다.
    MSG_CANNOT_FIND_SIGNATURE,          // 칩 서명을 찾을 수 없습니다.
    MSG_UNRECOGNIZED_SIGNATURE,         // 알 수 없는 서명입니다.
    MSG_BAD_START_ADDRESS,              // 파일 시작 주소가 잘못되었습니다.
    MSG_VERIFICATION_ERROR,             // 프로그래밍 후 확인 오류
    MSG_FUSE_PROBLEM,                   // 퓨즈 입력이 잘못되었거나 퓨즈 프로그래밍 문제
    MSG_FLASHED_OK,                     // 프로그래밍이 성공적으로 완료되었습니다.
} msgType;

const unsigned int ENTER_PROGRAMMING_ATTEMPTS = 2;

/* Port Setting Start ************************************/
// bit banged SPI pins
#ifdef __AVR_ATmega2560__
// Atmega2560
const byte MSPIM_SCK = 4;  // port G bit 5
const byte MSPIM_SS = 5;   // port E bit 3
const byte BB_MISO = 6;    // port H bit 3
const byte BB_MOSI = 7;    // port H bit 4
#elif defined(__AVR_ATmega1284P__)
// Atmega1284P
const byte MSPIM_SCK = 11;  // port D bit 3
const byte MSPIM_SS = 12;   // port D bit 4
const byte BB_MISO = 13;    // port D bit 5
const byte BB_MOSI = 14;    // port D bit 6
#else
// Atmega328
const byte MSPIM_SCK = 5;  // port D bit 5
const byte MSPIM_SS = 6;   // port D bit 6
const byte BB_MISO = 7;    // port D bit 7
const byte BB_MOSI = 8;    // port D bit 8
#endif

// 8 MHz clock on this pin
const byte CLOCKOUT = 9;

/*
대상 프로세서를 다음과 같이 연결하세요:
D5: (SCK) --> 데이터 시트에 따른 SCK
D6: (SS) --> 대상의 /RESET에 연결
D7: (MISO) --> 데이터 시트에 따른 MISO
D8: (MOSI) --> 데이터 시트에 따른 MOSI

D9: 대상에 필요한 경우 8 Mhz 클럭 신호

SD 카드를 다음과 같이 연결하세요:

D10: SS (칩 선택)
D11: MOSI (DI - SD 카드로 데이터 입력)
D12: MISO (DO - SD 카드에서 데이터 출력)
D13: SCK (CLK - 클럭)
SD 카드 및 대상 프로세서는 +5V 및 Gnd가 연결되어야 합니다.
D2와 Gnd 사이에 스위치를 연결하세요 (일반적으로 오픈 상태, 순간작동).
상태 LED:

A0: 빨간색 (오류) LED
A1: 녹색 (준비) LED
A2: 파란색 (작업 중) LED

각 LED에는 적절한 저항이 직렬로 연결되어야 합니다 (예: 220 옴).
LED의 다른 단자는 Gnd에 연결됩니다.
*/

// for fast port access
#ifdef __AVR_ATmega2560__
// Atmega2560
#define BB_MISO_PORT PINH
#define BB_MOSI_PORT PORTH
#define BB_SCK_PORT PORTG
const byte BB_SCK_BIT = 5;
const byte BB_MISO_BIT = 3;
const byte BB_MOSI_BIT = 4;
#elif defined(__AVR_ATmega1284P__)
// Atmega1284P
#define BB_MISO_PORT PIND
#define BB_MOSI_PORT PORTD
#define BB_SCK_PORT PORTD
const byte BB_SCK_BIT = 3;
const byte BB_MISO_BIT = 5;
const byte BB_MOSI_BIT = 6;
#else
// Atmega328
#define BB_MISO_PORT PIND
#define BB_MOSI_PORT PORTB
#define BB_SCK_PORT PORTD
const byte BB_SCK_BIT = 5;
const byte BB_MISO_BIT = 7;
const byte BB_MOSI_BIT = 0;
#endif

// 타겟 IC에 프로그래밍을 시작하는 데 필요한 스위치
const byte startSwitch = 2;

// 세 가지 동작 상태 LED
const int errorLED = A0;    // RED
const int readyLED = A1;    // GREEN
const int workingLED = A2;  // BLUE

const int noLED = -1;  // 음수가 될 수 있음으로 int 여야 합니다!

// 프로그래밍 속도를 제어 값을 너무 줄이면 프로그래밍에 실패할 가능성이있습니다
const byte BB_DELAY_MICROSECONDS = 6;

// 타겟 보드 리셋에 사용한 핀
const byte RESET = MSPIM_SS;
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

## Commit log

2024-04-23 내용수정
2024-04-23 3D 프린터용 케이스 STL
    [AVR_FLASHER - SLIM_BOT.STL, AVR_FLASHER - SLIM_HOLE.STL, AVR_FLASHER - SLIM_IO.STL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]
2024-04-23 사용하지 않는 라이브러리 제거
2024-04-24 퓨 즈비트를 설정할 수 있는 시험적 기능, 추후 추가 예정
2024-04-25 ATmega의 퓨즈 비트를 커스텀 할 수 있음
    CUSTOM_FUSE 와 IC 종류를 정의하고 ATmega의 퓨즈 비트를 커스텀 할 수 있음
    SD 카드의 설정 파일 부터 IC 와 퓨즈 비트 설정을 읽어오는 방식으로 구현하였으나 프로그래밍 속도에 영향을 주어 좀 더 연구가 필요함
2024-04-25 DEBUG 와 CUSTOM_FUSE 기능은 기본 false 로 변경
2024-04-25 타겟의 시그니처가 커스텀 퓨즈로 정의된 IC 정보와 일치하지 않는 경우
2024-04-25 Update README.md
    커스텀 퓨즈 사용법 업데이트
2024-04-25 ㅡㅡ;;
2024-04-27 디버그 레벨 추가, SD 카드 config.ini 파일로부터 커스텀 퓨즈비트 설정 읽어오는 기능 추가
    config.ini 퓨즈 비트 설정 양식
    ATmega328P:FFDEFDFF
    IC:Fuse (low/high/ext/lock)
2024-04-27 SD 카드 커스텀 퓨즈 사용법 추가
